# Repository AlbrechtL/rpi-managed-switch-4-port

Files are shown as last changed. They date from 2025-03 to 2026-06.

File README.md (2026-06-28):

# 4-Port Managed Switch

An open-source 4-port gigabit managed switch HAT based on a Raspberry Pi with OpenWrt support.

**Disclaimer:** This is an ongoing project where some features are not working, and some hardware bugs may exist.

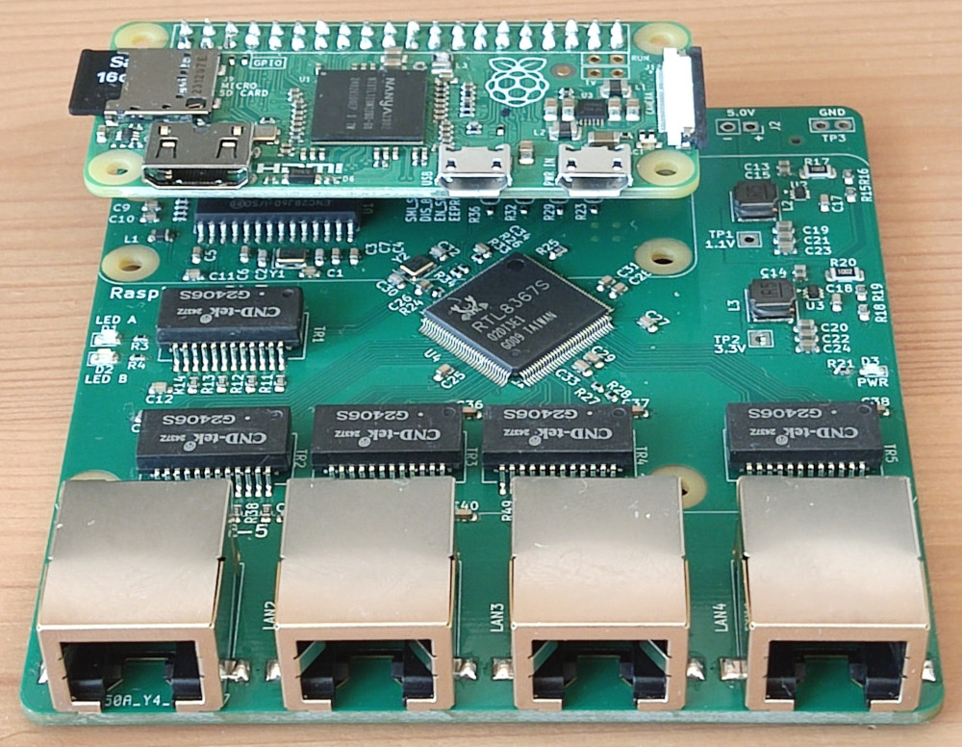
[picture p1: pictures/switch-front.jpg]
4 Port Managed Switch Front


## Features
* 4 Gigabit Ethernet RJ45 ports  
* Supports Raspberry Pi 1–5 (including Raspberry Pi Zero 1–2)  
  - Tested with a Raspberry Pi Zero 1  
  - Raspberry Pi 5 is not working with OpenWrt due to this [issue](https://github.com/openwrt/openwrt/issues/18034)  
* Works with a [custom OpenWrt](https://github.com/AlbrechtL/rpi-managed-switch-openwrt/tree/rpi_managed_switch)  
* Supported by Linux [Distributed Switch Architecture (DSA)](https://www.kernel.org/doc/Documentation/networking/dsa/dsa.txt)  
* VLAN support
* Switching hardware offloading support 
* Hardware design in KiCad
* Ready for JLCPCB production
  - Using a much as possible basic parts to lower the assembling costs

## Software Status

The hardware works with a adapted OpenWrt: https://github.com/AlbrechtL/openwrt/tree/rpi_managed_switch

I added the following to OpenWrt:  
* Device tree overlays for DSA
* Enabled the ENC28J60 driver 
* Added a small patch to enable the ENC28J60 for DSA  
* Added detection of DSA in the first boot scripts so that OpenWrt uses the switch  

See the differences:  
https://github.com/openwrt/openwrt/compare/main...AlbrechtL:openwrt:rpi_managed_switch  

Communication with the RTL8367S switch chip uses Linux DSA. There is also an OpenWrt-specific driver (`drivers/net/phy/rtl8367b.c`) for OpenWrt's legacy `swconfig` framework, but since OpenWrt is moving to DSA, it does not make sense to use it in this project. That said, this driver does work with this switch.

**Distributed Switch Architecture (DSA)**

The to go Linux driver is: `drivers/net/dsa/realtek/rtl8365mb.c`
* Key aspects:
  - Integrated into the Linux kernel  
  - Mainline RTL8367S support  
  - Works on Raspberry Pi OS with a custom Linux kernel
  - Actively maintained
  - Hardware offloading and VLAN support
    - May be added into Linux 7.2 (https://lore.kernel.org/all/20260606-realtek_forward-v13-0-b9e409687cbe@gmail.com/)
    - Available in mainline OpenWrt (https://github.com/openwrt/openwrt/pull/23738)

DSA Example:
```
root@OpenWrt:~# ip addr
1: lo: <LOOPBACK,UP,LOWER_UP> mtu 65536 qdisc noqueue state UNKNOWN qlen 1000
    link/loopback 00:00:00:00:00:00 brd 00:00:00:00:00:00
    inet 127.0.0.1/8 scope host lo
       valid_lft forever preferred_lft forever
    inet6 ::1/128 scope host 
       valid_lft forever preferred_lft forever
2: eth0: <BROADCAST,MULTICAST,UP,LOWER_UP> mtu 1508 qdisc fq_codel state UP qlen 1000
    link/ether b8:27:eb:8f:43:df brd ff:ff:ff:ff:ff:ff
    inet6 fe80::ba27:ebff:fe8f:43df/64 scope link 
       valid_lft forever preferred_lft forever
3: lan1@eth0: <BROADCAST,MULTICAST,UP,LOWER_UP> mtu 1500 qdisc noqueue master switch state UP qlen 1000
    link/ether b8:27:eb:8f:43:df brd ff:ff:ff:ff:ff:ff
4: lan2@eth0: <NO-CARRIER,BROADCAST,MULTICAST,UP> mtu 1500 qdisc noqueue master switch state DOWN qlen 1000
    link/ether b8:27:eb:8f:43:e0 brd ff:ff:ff:ff:ff:ff
5: lan3@eth0: <NO-CARRIER,BROADCAST,MULTICAST,UP> mtu 1500 qdisc noqueue master switch state DOWN qlen 1000
    link/ether b8:27:eb:8f:43:e1 brd ff:ff:ff:ff:ff:ff
6: lan4@eth0: <BROADCAST,MULTICAST,UP,LOWER_UP> mtu 1500 qdisc noqueue master switch state UP qlen 1000
    link/ether b8:27:eb:8f:43:e2 brd ff:ff:ff:ff:ff:ff
7: switch: <BROADCAST,MULTICAST,UP,LOWER_UP> mtu 1500 qdisc noqueue state UP qlen 1000
    link/ether b8:27:eb:8f:43:df brd ff:ff:ff:ff:ff:ff
    inet6 fe80::ba27:ebff:fe8f:43df/64 scope link 
       valid_lft forever preferred_lft forever
8: switch.1@switch: <BROADCAST,MULTICAST,UP,LOWER_UP> mtu 1500 qdisc noqueue state UP qlen 1000
    link/ether b8:27:eb:8f:43:df brd ff:ff:ff:ff:ff:ff
    inet 192.168.1.1/24 brd 192.168.1.255 scope global switch.1
       valid_lft forever preferred_lft forever
    inet6 fd8d:3fdb:486f::1/60 scope global noprefixroute 
       valid_lft forever preferred_lft forever
    inet6 fe80::ba27:ebff:fe8f:43df/64 scope link 
       valid_lft forever preferred_lft forever
```

OpenWrt DSA screenshot  
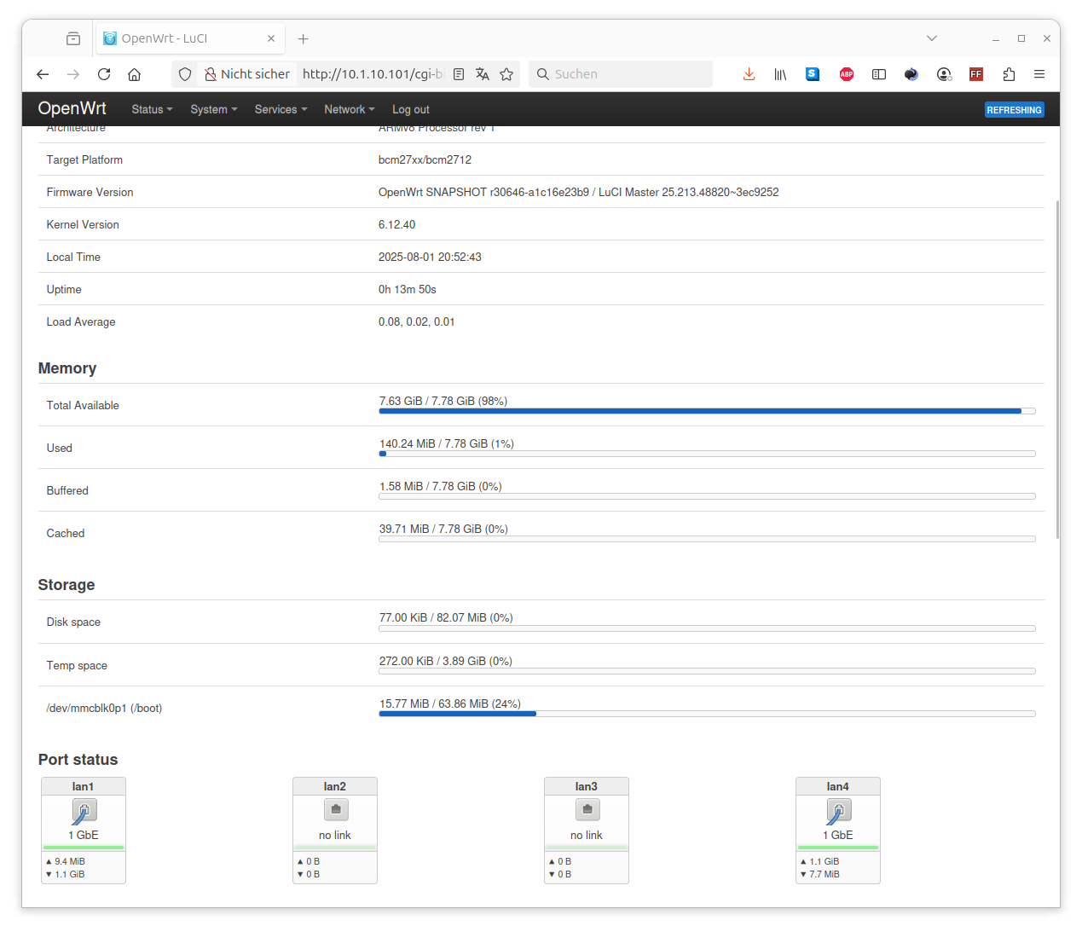
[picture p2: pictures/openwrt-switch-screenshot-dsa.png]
OpenWrt dsa
  

## Hardware Status

I have two assembled PCBs that have basic functionality. See [issues](https://github.com/AlbrechtL/rpi-managed-switch-4-port/issues) for a list of hardware problems.

**Raspberry Pi Zero**
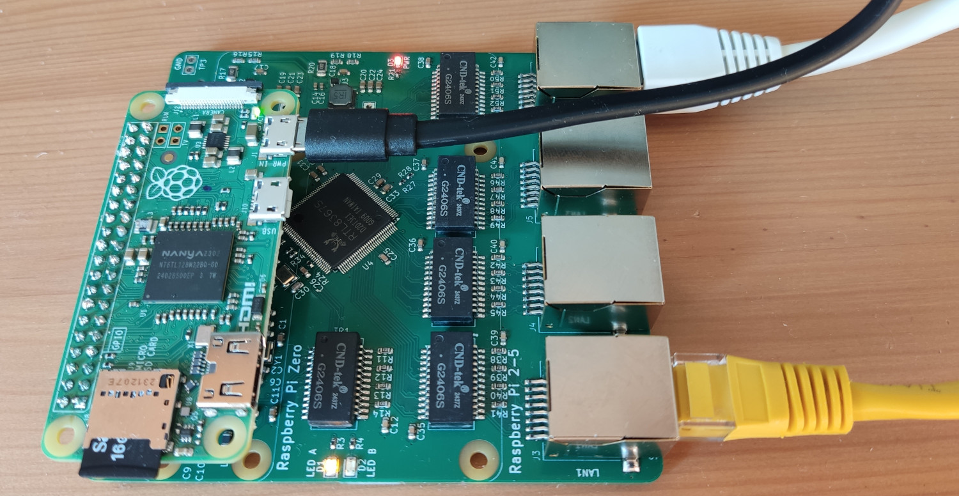
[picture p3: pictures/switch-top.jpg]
4 Port Managed Switch Top


**Raspberry Pi 5**
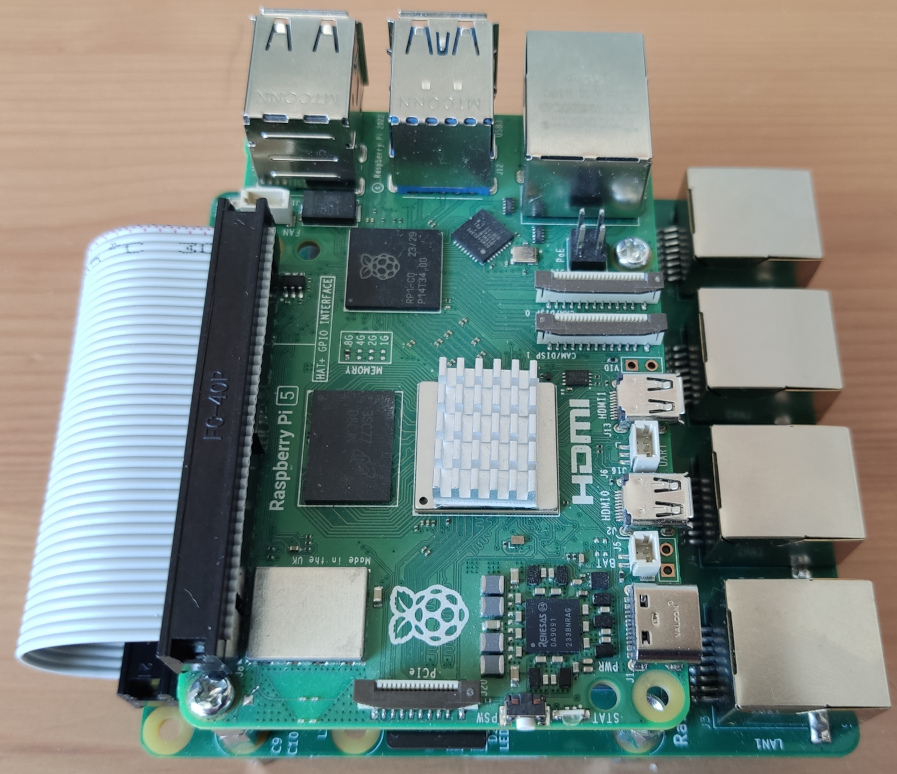
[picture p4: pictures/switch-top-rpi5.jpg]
4 Port Managed Switch Top


## Performance

I don't have detailed performance measurements yet, but here are some bandwidth indications:  
* **RJ45–RJ45 with DSA (rtl8365mb) and offloading patches:** ~1 Gbit/s (wire speed, full-duplex)   
* **RJ45–RJ45 with DSA (rtl8365mb):** ~2 Mbit/s  
  Currently, the RTL8367S DSA driver doesn't support hardware offloading. As a result, all traffic is routed through the Raspberry Pi and the very slow SPI interface. For a switch, this is not acceptable.  
* **Raspberry Pi to RJ45 (CPU port):** ~5 Mbit/s (half-duplex)  
  To support the inexpensive Raspberry Pi Zero, an external SPI Ethernet chip (ENC28J60) is used to connect to the main switch chip (RTL8367S). Due to the slow SPI interface, only ~5 Mbit/s can be achieved. However, for a managed web interface, that's sufficient.  

## Acknowledgements

I would like to thank the following open-source projects. Without these great works, this open-source switch would not be possible:  
* [OpenWrt](https://openwrt.org/)  
* RTL8367S Managed Switch  
  - Blog post: https://blog.brixit.nl/making-a-linux-managed-network-switch/  
  - KiCad: https://github.com/FOSDEM/video/tree/master/hardware/pcbs/switch_board  
* ENC28J60 on a Raspberry Pi Zero  
  - Hackster: https://www.hackster.io/lightside-instruments/the-ethernet4pizero-ethernet-for-raspberry-pi-zero-shield-dd4316  
  - KiCad: https://github.com/lightside-instruments/ethernet4pizero.git  
* [RPI5-CFE-Hat](https://github.com/will127534/RPI5-CFE-Hat)  
* [PCIe3_Hub](https://github.com/will127534/PCIe3_Hub)  
* [RouterPi](https://github.com/ZakKemble/RouterPi)

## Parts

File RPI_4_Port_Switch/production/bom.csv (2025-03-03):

Designator | Footprint | Quantity | Value | LCSC Part #
C1, C10, C11, C17, C18, C25, C26, C27, C28, C29, C31, C33, C34, C35, C36, C37, C38, C4, C5, C6, C7, C9 | 0603 | 22 | 100nF | C14663
C12, C39, C40, C41, C42 | 0603 | 5 | 1nF | C1588
C13, C14, C15, C16, C8 | 0402 | 5 | 10uF | C15525
C19, C20, C21, C22, C23, C24 | 0603 | 6 | 22uF | C59461
C2, C3, C30, C32 | 0603 | 4 | 18pF | C1647
D1 | 0805 | 1 | Yellow | C2296
D2 | 0805 | 1 | Green | C2297
D3 | 0603 | 1 | Red | C2286
H1, H2, H3, H4, H5, H6, H7, H8 | screw_hole | 8 | MountingHole
J1 | PinSocket_2x20_P2.54mm_Vertical_1_04mm | 1 | Raspberry_Pi_2_3
J2 | PinSocket_1x02_P2.54mm_Vertical | 1 | Conn_01x02
J3, J4, J5, J6 | Heling MJ88-B211-JRS3 | 4 | 8P8C_LED | C2895614
L1 | 0805 | 1 | Ferrite Beads | C1015
L2, L3 | L_Taiyo-Yuden_MD-5050 | 2 | 1.5uH | C702825
R1, R17, R2, R20 | 1206 | 4 | 10k | C17902
R10, R7, R8, R9 | 0402 | 4 | 49.9 | C25120
R11, R12, R13, R14, R38, R39, R40, R41, R42, R43, R44, R45, R46, R47, R48, R49, R50, R51, R52, R53 | 0603 | 20 | 75 | C4275
R15 | 0603 | 1 | 3.3k | C22978
R16 | 0603 | 1 | 4.99k | C23046
R18 | 0603 | 1 | 6.2k | C4260
R19 | 0603 | 1 | 39k | C23153
R21, R28, R3, R4 | 0402 | 4 | 470 | C25117
R22, R23, R24, R26, R29, R30, R31, R32, R33, R34, R35, R36, R37 | 0402 | 13 | 4.7k | C25900
R25 | 0603 | 1 | 1k | C21190
R27, R5 | 0402 | 2 | 2k | C4109
R6 | 0402 | 1 | 330 | C25104
TP3 | TestPoint_Bridge_Pitch2.54mm_Drill1.0mm | 1 | Ground point
TR1, TR2, TR3, TR4, TR5 | G2406S | 5 | G2406S | C507595
U1 | SOIC-28W_7.5x17.9mm_P1.27mm | 1 | ENC28J60-I/SO | C47351
U2, U3 | SOT-563 | 2 | TPS562231 | C2070899
U4 | LQFP-128_14x14mm_P0.4mm | 1 | RTL8367S | C2760849
Y1, Y2 | Crystal_SMD_Abracon_ABM8G-4Pin_3.2x2.5mm | 2 | 25Mhz | C9006

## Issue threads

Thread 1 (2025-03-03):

Pull-up resistor at RTL_MDC missing

AlbrechtL, 2025-03-03:
The pull-up resistor at the RTL_MDC line (pin 87 at RTL8367S) is missing. As a result the RTL8367S SMI detection and communication is unstable.

- [x] Fixed in schematic
- [ ] Fixed in PCB

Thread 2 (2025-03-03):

Add USB to Raspberry Pi UART interface

AlbrechtL, 2025-03-03:
To have Ethernet independent access the Raspberry Pi UART pins can be used. When the Raspberry Pi Zero is attached those pins are not accessible easily.

As a convenience feature a USB plug and a USB to UART interface would be really nice.

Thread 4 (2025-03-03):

Add Ethernet LEDs

AlbrechtL, 2025-03-03:
In the first design, the Ethernet LEDs are missing to keep the initial design simple.

In the next design, the Ethernet LEDs shall be existing to give the user feedback about the link status and the activity.

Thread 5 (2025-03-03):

LED brightness too high

AlbrechtL, 2025-03-03:
The brightness of the LEDs "PWR", "RPi ETH Link" and "RPi ETH Activity" are too high. They are dazzling the eyes.

- [ ] Fixed in schematic
- [ ] Fixed in PCB

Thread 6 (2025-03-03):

Use correct part for J1 and J2 connector

AlbrechtL, 2025-03-03:
At the PCB the J1 and J2 connector are using wrong parts. During initial production, this was not an issue because those parts are not assembled by JLCPCB. The footprint itself is working as expected.

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

- [ ] Fixed in schematic
- [ ] Fixed in PCB

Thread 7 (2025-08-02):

LAN3 not working

AlbrechtL, 2025-08-02:
It seems that LAN3 is not working. The reason is unclear - further investigations are needed.

Tested with OpenWrt https://github.com/AlbrechtL/openwrt/tree/rpi_managed_switch and `rtl8365mb.c` patches.

namiltd, 2025-09-09:
change:
```
+		/* 10th register uses only 4 less significant bits (TODO: not tested) */
+		if (val_size == 10)
+			ret = regmap_update_bits(priv->map,
+					RTL8365MB_TABLE_WRITE_DATA_REG_BASE,
+					RTL8365MB_TABLE_10TH_DATA_REG_MASK,
+					FIELD_PREP(RTL8365MB_TABLE_10TH_DATA_REG_MASK, val[9]));
+		if (ret)
+			goto out;
```
to
```
+		/* 10th register uses only 4 less significant bits (TODO: not tested) */
+		if (val_size == 10)
+			ret = regmap_update_bits(priv->map,
+					RTL8365MB_TABLE_WRITE_DATA_REG_BASE + 9,
+					RTL8365MB_TABLE_10TH_DATA_REG_MASK,
+					FIELD_PREP(RTL8365MB_TABLE_10TH_DATA_REG_MASK, val[9]));
+		if (ret)
+			goto out;
```

namiltd, 2025-09-09:
Next test:
```
+	for (vlanmc_idx = 1; vlanmc_idx < RTL8365MB_VLAN_MC_CONF_SIZE; vlanmc_idx++) {
+		ret = regmap_bulk_read(priv->map,
+				       RTL8365MB_VLAN_MC_CONF_REG(vlanmc_idx),
+				       &vlan_entry,
+				       RTL8365MB_VLAN_MC_CONF_ENTRY_SIZE);
+		if (ret) {
+			if (extack)
+				NL_SET_ERR_MSG_MOD(extack,
+						   "Failed to read vlan MC entry");
+			return ret;
+		}
```
to
```
+	for (vlanmc_idx = 1; vlanmc_idx < RTL8365MB_VLAN_MC_CONF_SIZE; vlanmc_idx++) {
+		ret = regmap_bulk_read(priv->map,
+				       RTL8365MB_VLAN_MC_CONF_REG(vlanmc_idx),
+				       vlan_entry,
+				       RTL8365MB_VLAN_MC_CONF_ENTRY_SIZE);
+		if (ret) {
+			if (extack)
+				NL_SET_ERR_MSG_MOD(extack,
+						   "Failed to read vlan MC entry");
+			return ret;
+		}
```

AlbrechtL, 2025-09-09:
I applied all your changes. Still no luck.

But, I'm not sure if I did it correctly. Here is my resulting [rtl8365mb.c](https://github.com/user-attachments/files/22230778/rtl8365mb.c) (kernel 6.12).

AlbrechtL, 2025-09-09:
All other ports are working. Here is my OpenWrt network config. Maybe it is related with the VLAN config.

```
root@OpenWrt:~# cat /etc/config/network

config interface 'loopback'
	option device 'lo'
	option proto 'static'
	list ipaddr '127.0.0.1/8'

config globals 'globals'
	option ula_prefix 'fdbc:dcd7:a884::/48'
	option packet_steering '1'

config device 'switch'
	option name 'switch'
	option type 'bridge'
	option macaddr 'b8:27:eb:8f:43:df'

config bridge-vlan 'lan_vlan'
	option device 'switch'
	option vlan '1'
	option ports 'lan1 lan2 lan3 lan4'

config device
	option name 'switch.1'
	option macaddr 'b8:27:eb:8f:43:df'

config interface 'lan'
	option device 'switch.1'
	option proto 'dhcp'

root@OpenWrt:~#
```

namiltd, 2025-09-09:
`apk add ip-bridge` or `opkg install ip-bridge` and then `bridge vlan show`

namiltd, 2025-09-10:
Everything seems to be fine, but it doesn't work, it's a mystery.

AlbrechtL, 2025-09-10:
Does it work on your TP-Link Archer C5 v4 or EC220-G5 v2 hardware?

namiltd, 2025-09-10:
I'm struggling with frequent crashes on Archer C5 v4 with kernel 6.12 (even without DSA). I   haven't tested the functionality of individual LANs. I'll first resolve the crash issue and then further tests.

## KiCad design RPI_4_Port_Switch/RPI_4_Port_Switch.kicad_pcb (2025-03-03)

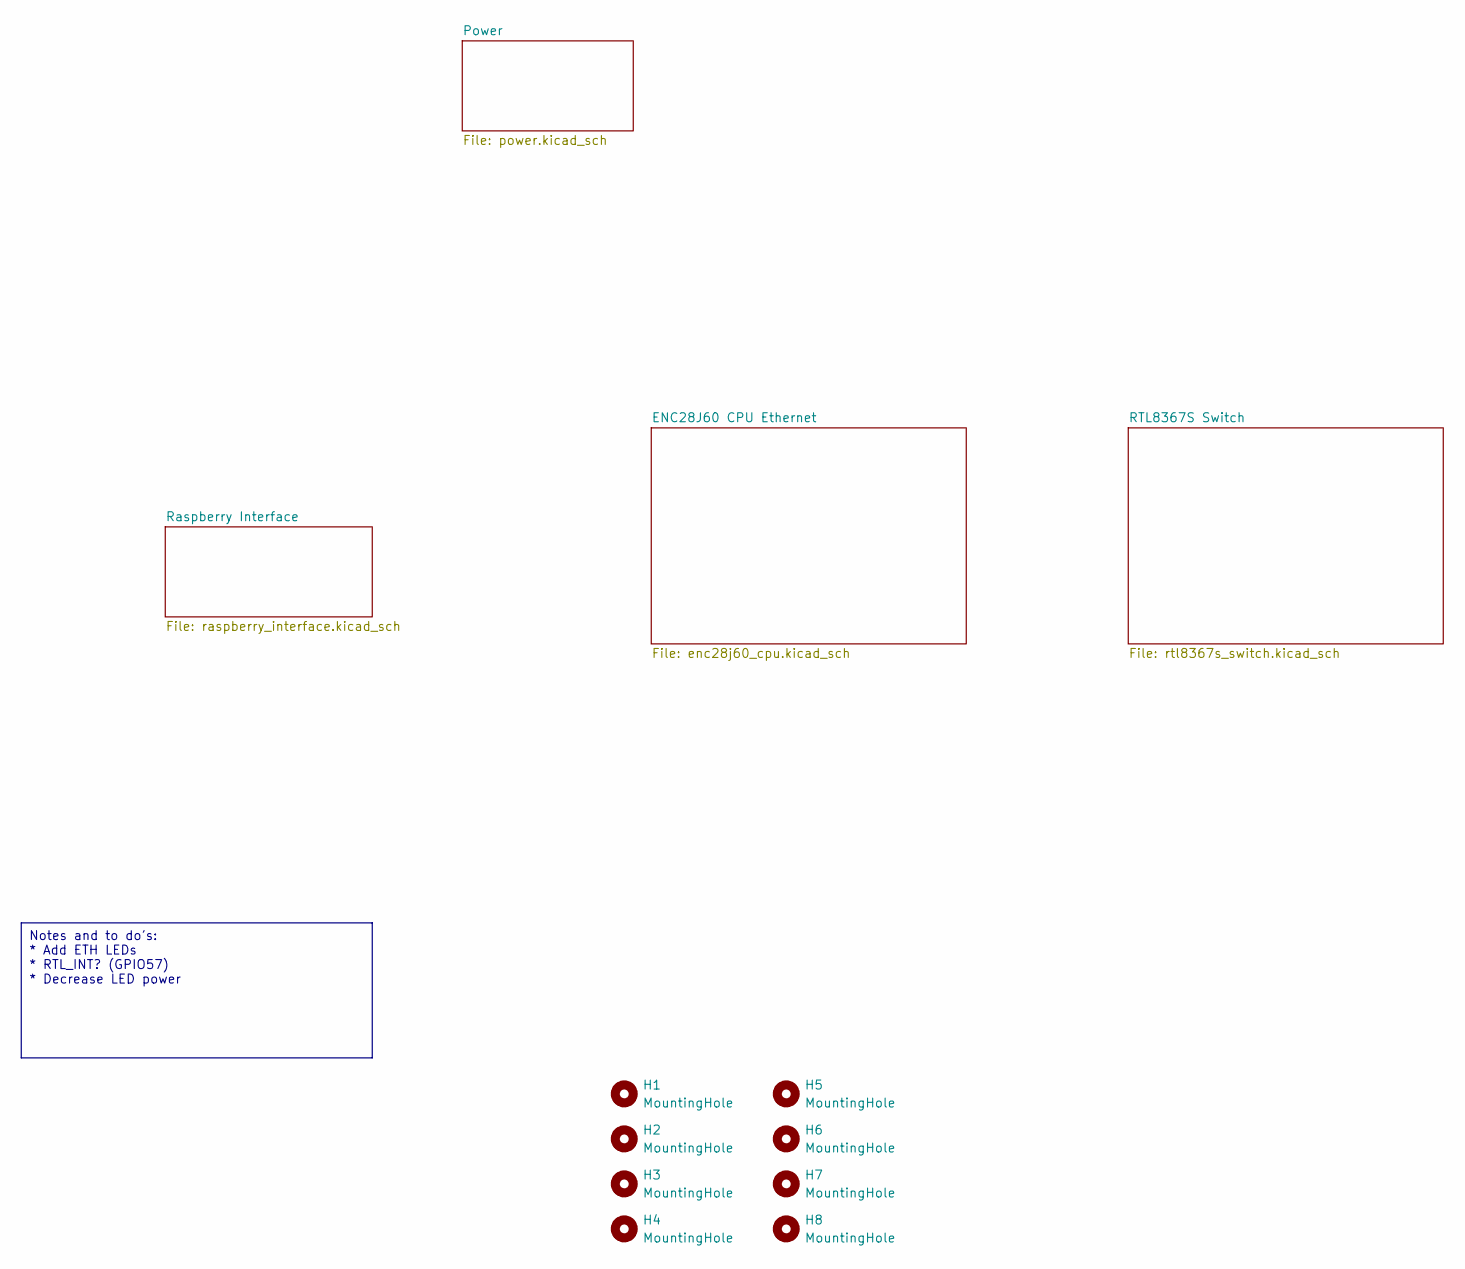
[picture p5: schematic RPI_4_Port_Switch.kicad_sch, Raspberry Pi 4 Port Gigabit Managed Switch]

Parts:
H1, H2, H3, H4, H5, H6, H7, H8: MountingHole; screw_hole

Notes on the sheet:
Notes and to do's: * Add ETH LEDs * RTL_INT? (GPIO57) * Decrease LED power

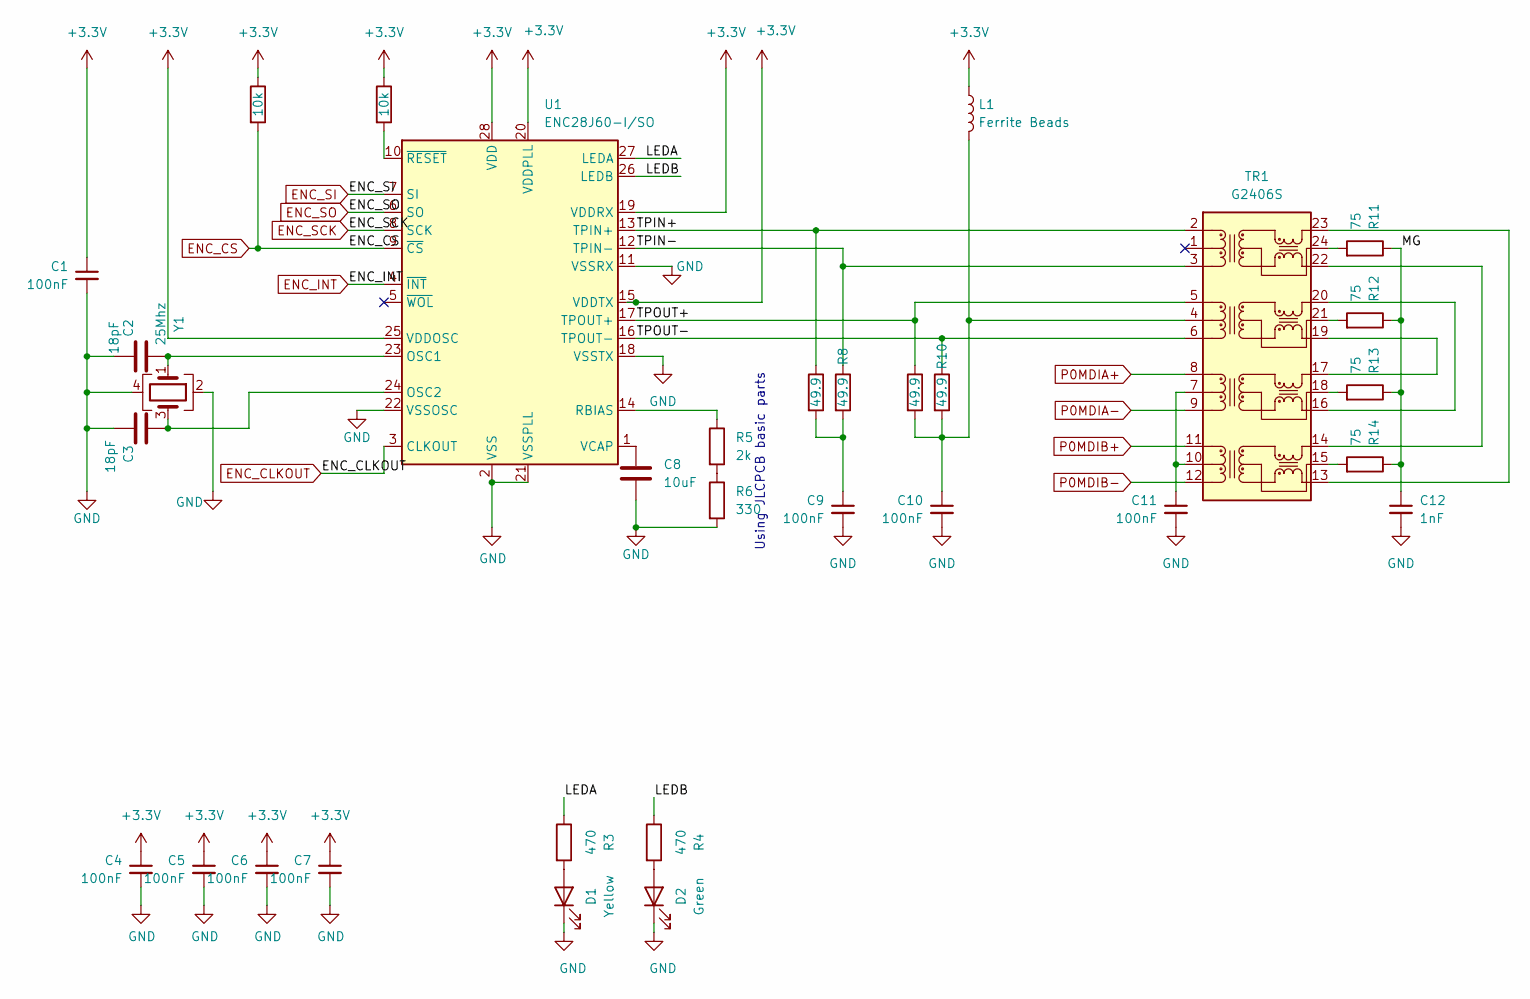
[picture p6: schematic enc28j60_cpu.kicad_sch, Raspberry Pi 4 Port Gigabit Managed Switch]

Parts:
C1, C4, C5, C6, C7, C9, C10, C11: 100nF; C_0603_1608Metric; Part 50V 100nF X7R ±10% 0603; LCSC Part # C14663
C2, C3: 18pF; C_0603_1608Metric; Part 50V 18pF C0G ±5% 0603; LCSC Part # C1647
C8: 10uF; C_0402_1005Metric; Part 6.3V 10uF X5R ±20% 0402; LCSC Part # C15525
C12: 1nF; C_0603_1608Metric; Part 50V 1nF X7R ±10% 0603; LCSC Part # C1588
D1: Yellow; LED_0805_2012Metric; Part Yellow 0805 LED Indication; LCSC Part # C2296
D2: Green; LED_0805_2012Metric; Part Emerald 0805 LED Indication (green); LCSC Part # C2297
L1: Ferrite Beads; L_0805_2012Metric; LCSC Part # C1015
R1, R2: 10k; R_1206_3216Metric; Part 250mW Thick Film Resistors 200V ±100ppm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; LCSC Part # C17902
R3, R4: 470; R_0402_1005Metric; Part 62.5mW Thick Film Resistors 50V ±100ppm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; LCSC Part # C25117
R5: 2k; R_0402_1005Metric; Part 62.5mW Thick Film Resistors 50V ±100ppm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; LCSC Part # C4109
R6: 330; R_0402_1005Metric; Part 62.5mW Thick Film Resistors 50V ±100ppm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; LCSC Part # C25104
R7, R8, R9, R10: 49.9; R_0402_1005Metric; Part 62.5mW Thick Film Resistors 50V ±100ppm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; LCSC Part # C25120
R11, R12, R13, R14: 75; R_0603_1608Metric; Part R 75Ω 125mW 1% 0603; LCSC Part # C4275
TR1: G2406S; Part G2406S; LCSC Part # C507595
U1: ENC28J60-I/SO; SOIC-28W_7.5x17.9mm_P1.27mm; LCSC Part # C47351
Y1: 25Mhz; Crystal_SMD_Abracon_ABM8G-4Pin_3.2x2.5mm; LCSC Part # C9006

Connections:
+3.3V: C1.1, C4.1, C5.1, C6.1, C7.1, L1.1, R1.1, R2.1, U1.15 (VDDTX), U1.19 (VDDRX), U1.20 (VDDPLL), U1.25 (VDDOSC), U1.28 (VDD); also elsewhere on the board
/ENC28J60 CPU Ethernet/LEDA: R3.1, U1.27 (LEDA)
/ENC28J60 CPU Ethernet/LEDB: R4.1, U1.26 (LEDB)
/ENC28J60 CPU Ethernet/MG: C12.1, R11.1, R12.1, R13.1, R14.1
/ENC28J60 CPU Ethernet/TPIN+: R7.1, TR1.2 (TD1+), U1.13 (TPIN+)
/ENC28J60 CPU Ethernet/TPIN-: R8.1, TR1.3 (TD1-), U1.12 (TPIN-)
/ENC28J60 CPU Ethernet/TPOUT+: R9.1, TR1.5 (TD2+), U1.17 (TPOUT+)
/ENC28J60 CPU Ethernet/TPOUT-: R10.1, TR1.6 (TD2-), U1.16 (TPOUT-)
ENC_CLKOUT: U1.3 (CLKOUT); also elsewhere on the board
ENC_CS: R1.2, U1.9 (~CS); also elsewhere on the board
ENC_INT: U1.4 (~INT); also elsewhere on the board
ENC_SCK: U1.8 (SCK); also elsewhere on the board
ENC_SI: U1.7 (SI); also elsewhere on the board
ENC_SO: U1.6 (SO); also elsewhere on the board
GND: C1.2, C2.2, C3.2, C4.2, C5.2, C6.2, C7.2, C8.2, C9.2, C10.2, C11.2, C12.2, D1.1 (K), D2.1 (K), R6.2, U1.2 (VSS), U1.11 (VSSRX), U1.18 (VSSTX), U1.21 (VSSPLL), U1.22 (VSSOSC), Y1.2, Y1.4; also elsewhere on the board
unnamed: C9.1, R7.2, R8.2
unnamed: C10.1, L1.2, R9.2, R10.2, TR1.4 (CT)
unnamed: C11.1, TR1.7 (CT), TR1.10 (CT)
unnamed: D1.2 (A), R3.2
unnamed: D2.2 (A), R4.2
unnamed: R5.2, R6.1
unnamed: R11.2, TR1.24 (CT)
unnamed: R12.2, TR1.21 (CT)
unnamed: R13.2, TR1.18 (CT)
unnamed: R14.2, TR1.15 (CT)
unnamed: TR1.13 (MX4-), TR1.23 (MX1+)
unnamed: TR1.14 (MX4+), TR1.22 (MX1-)
unnamed: TR1.16 (MX3-), TR1.20 (MX2+)
unnamed: TR1.17 (MX3+), TR1.19 (MX2-)
unnamed: C2.1, U1.23 (OSC1), Y1.1
unnamed: C3.1, U1.24 (OSC2), Y1.3
unnamed: R5.1, U1.14 (RBIAS)
unnamed: C8.1, U1.1 (VCAP)
unnamed: R2.2, U1.10 (~RESET)
P0MDIA+: TR1.8 (TD3+); also elsewhere on the board
P0MDIA-: TR1.9 (TD3-); also elsewhere on the board
P0MDIB+: TR1.11 (TD4+); also elsewhere on the board
P0MDIB-: TR1.12 (TD4-); also elsewhere on the board

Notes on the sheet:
Using JLCPCB basic parts

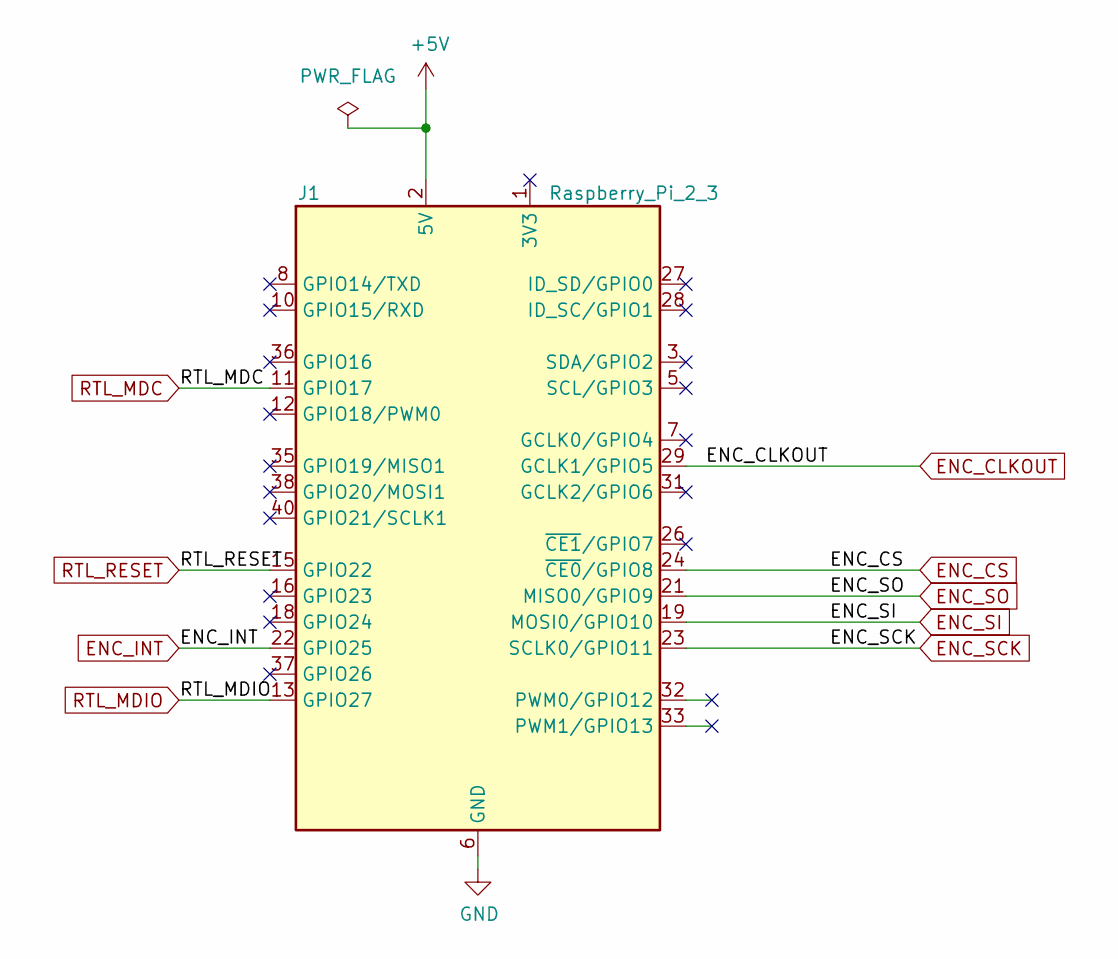
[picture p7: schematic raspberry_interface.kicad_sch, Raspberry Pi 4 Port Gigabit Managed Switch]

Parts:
J1: Raspberry_Pi_2_3; PinSocket_2x20_P2.54mm_Vertical_1_04mm

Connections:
+5V: J1.2 (5V), J1.4 (5V); also elsewhere on the board
ENC_CLKOUT: J1.29 (GCLK1/GPIO5); also elsewhere on the board
ENC_CS: J1.24 (~CE0/GPIO8); also elsewhere on the board
ENC_INT: J1.22 (GPIO25); also elsewhere on the board
ENC_SCK: J1.23 (SCLK0/GPIO11); also elsewhere on the board
ENC_SI: J1.19 (MOSI0/GPIO10); also elsewhere on the board
ENC_SO: J1.21 (MISO0/GPIO9); also elsewhere on the board
GND: J1.6 (GND), J1.9 (GND), J1.14 (GND), J1.20 (GND), J1.25 (GND), J1.30 (GND), J1.34 (GND), J1.39 (GND); also elsewhere on the board
RTL_MDC: J1.11 (GPIO17); also elsewhere on the board
RTL_MDIO: J1.13 (GPIO27); also elsewhere on the board
RTL_RESET: J1.15 (GPIO22); also elsewhere on the board

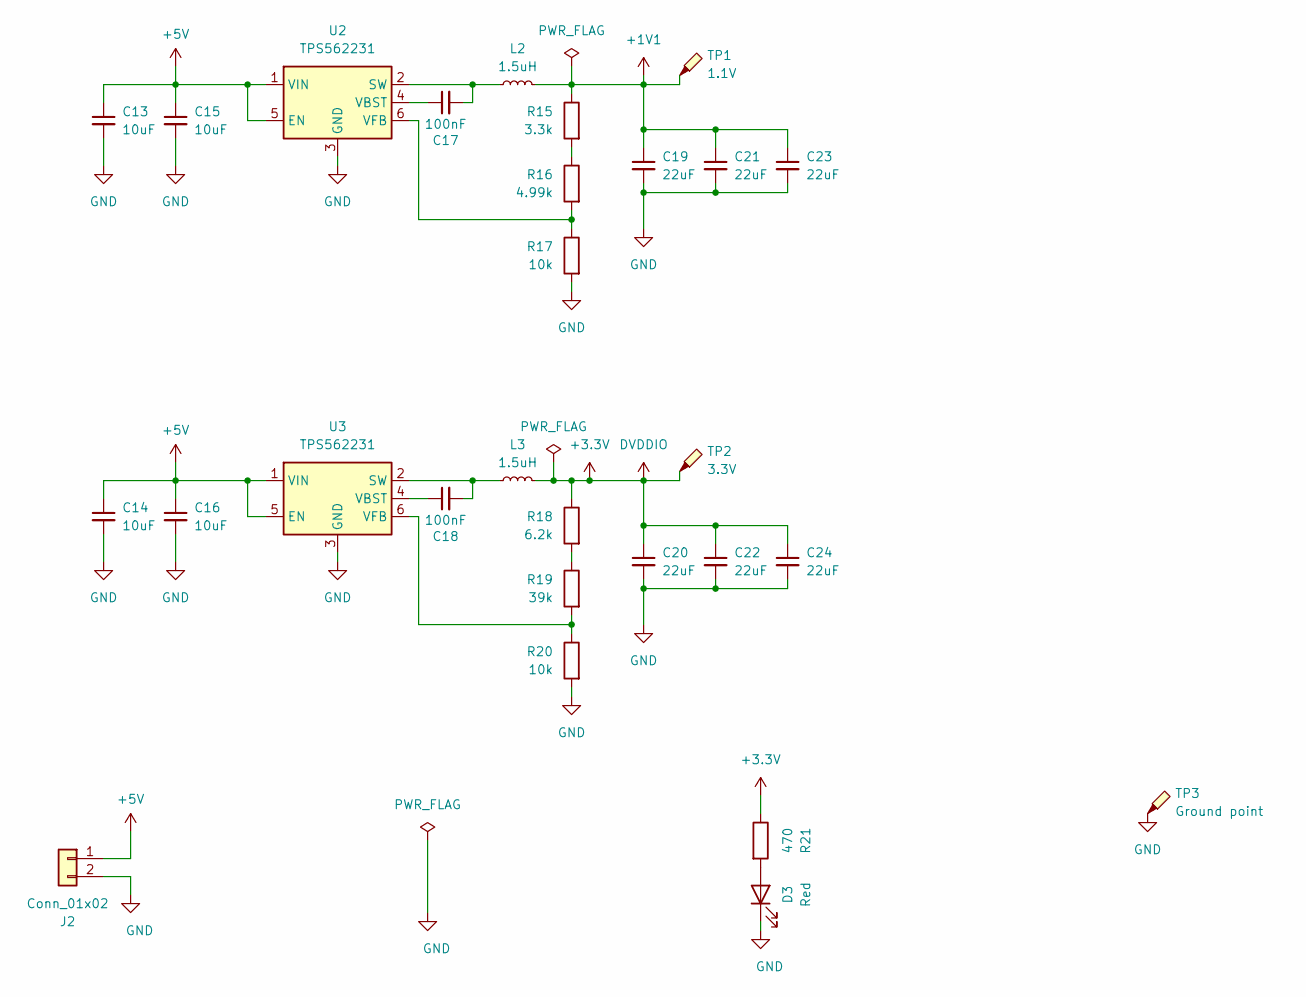
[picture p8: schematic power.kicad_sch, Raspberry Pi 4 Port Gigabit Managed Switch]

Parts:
C13, C14, C15, C16: 10uF; C_0402_1005Metric; Part 6.3V 10uF X5R ±20% 0402; LCSC Part # C15525
C17, C18: 100nF; C_0603_1608Metric; Part 50V 100nF X7R ±10% 0603; LCSC Part # C14663
C19, C20, C21, C22, C23, C24: 22uF; C_0603_1608Metric; Part 6.3V 22uF X5R ±20% 0603; LCSC Part # C59461
D3: Red; LED_0603_1608Metric; Part LED Red 0603; LCSC Part # C2286
J2: Conn_01x02; PinSocket_1x02_P2.54mm_Vertical
L2, L3: 1.5uH; L_Taiyo-Yuden_MD-5050; Part BWVF005050201R5T00 or 74404054015; LCSC Part # C702825
R15: 3.3k; R_0603_1608Metric; Part R 3.3kΩ 125mW 1% 0603; LCSC Part # C22978
R16: 4.99k; R_0603_1608Metric; Part R 4.99kΩ 125mW 1% 0603; LCSC Part # C23046
R17, R20: 10k; R_1206_3216Metric; Part 250mW Thick Film Resistors 200V ±100ppm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; LCSC Part # C17902
R18: 6.2k; R_0603_1608Metric; Part R 6.2kΩ 125mW 1% 0603; LCSC Part # C4260
R19: 39k; R_0603_1608Metric; Part R 39kΩ 125mW 1% 0603; LCSC Part # C23153
R21: 470; R_0402_1005Metric; Part 62.5mW Thick Film Resistors 50V ±100ppm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; LCSC Part # C25117
TP1: 1.1V; TestPoint_THTPad_2.0x2.0mm_Drill1.0mm
TP2: 3.3V; TestPoint_THTPad_2.0x2.0mm_Drill1.0mm
TP3: Ground point; TestPoint_Bridge_Pitch2.54mm_Drill1.0mm
U2, U3: TPS562231; SOT-563; Part TPS562231DRLR; LCSC Part # C2070899

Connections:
+1V1: C19.1, C21.1, C23.1, L2.2, R15.1, TP1.1; also elsewhere on the board
+3.3V: C20.1, C22.1, C24.1, L3.2, R18.1, R21.1, TP2.1; also elsewhere on the board
+5V: C13.1, C14.1, C15.1, C16.1, J2.1, U2.1 (VIN), U2.5 (EN), U3.1 (VIN), U3.5 (EN); also elsewhere on the board
GND: C13.2, C14.2, C15.2, C16.2, C19.2, C20.2, C21.2, C22.2, C23.2, C24.2, D3.1 (K), J2.2, R17.2, R20.2, TP3.1, U2.3 (GND), U3.3 (GND); also elsewhere on the board
unnamed: D3.2 (A), R21.2
unnamed: R15.2, R16.1
unnamed: R18.2, R19.1
unnamed: C17.2, L2.1, U2.2 (SW)
unnamed: C17.1, U2.4 (VBST)
unnamed: R16.2, R17.1, U2.6 (VFB)
unnamed: C18.2, L3.1, U3.2 (SW)
unnamed: C18.1, U3.4 (VBST)
unnamed: R19.2, R20.1, U3.6 (VFB)

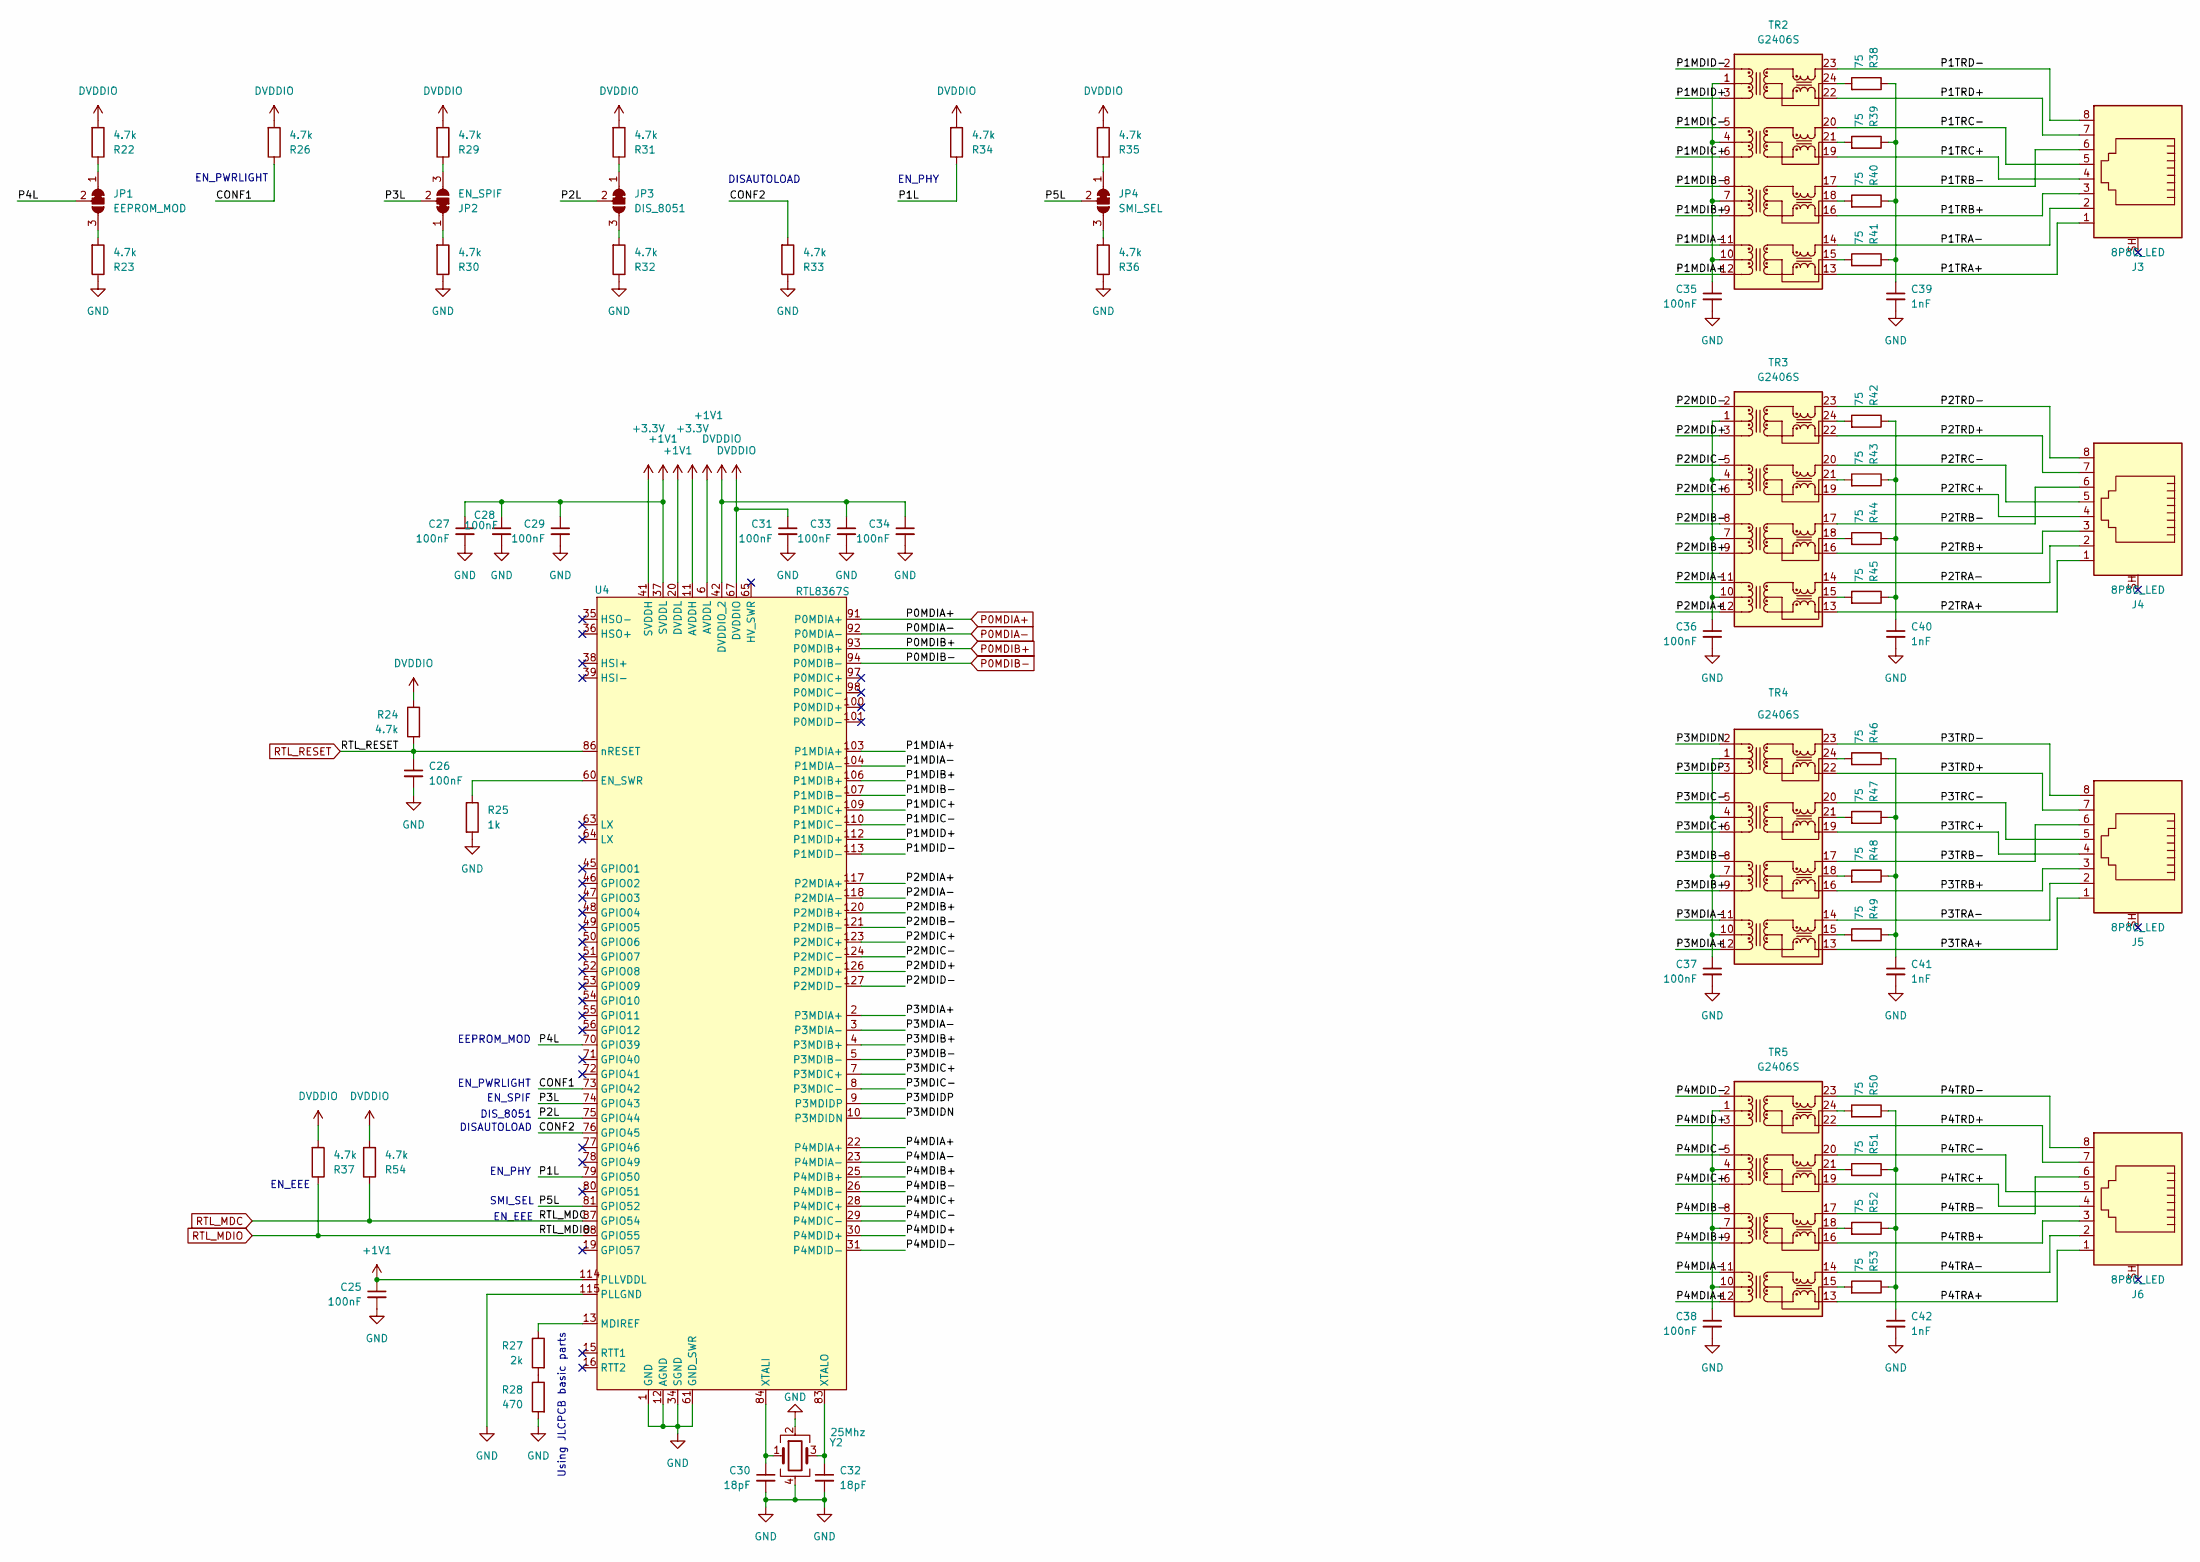
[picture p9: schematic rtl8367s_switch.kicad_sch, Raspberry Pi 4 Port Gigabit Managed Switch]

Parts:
C25, C26, C27, C28, C29, C31, C33, C34, C35, C36, C37, C38: 100nF; C_0603_1608Metric; Part 50V 100nF X7R ±10% 0603; LCSC Part # C14663
C30, C32: 18pF; C_0603_1608Metric; Part 50V 18pF C0G ±5% 0603; LCSC Part # C1647
C39, C40, C41, C42: 1nF; C_0603_1608Metric; Part 50V 1nF X7R ±10% 0603; LCSC Part # C1588
J3, J4, J5, J6: 8P8C_LED; Heling MJ88-B211-JRS3; Part MJ88-B211-JRS3; LCSC Part # C2895614
JP1: EEPROM_MOD; SolderJumper-3_P1.3mm_Bridged12_RoundedPad1.0x1.5mm
JP2: EN_SPIF; SolderJumper-3_P1.3mm_Bridged12_RoundedPad1.0x1.5mm
JP3: DIS_8051; SolderJumper-3_P1.3mm_Bridged12_RoundedPad1.0x1.5mm
JP4: SMI_SEL; SolderJumper-3_P1.3mm_Bridged12_RoundedPad1.0x1.5mm
R22, R23, R24, R26, R29, R30, R31, R32, R33, R34, R35, R36, R37, R54: 4.7k; R_0402_1005Metric; LCSC Part # C25900
R25: 1k; R_0603_1608Metric; Part R 1kΩ 125mW 1% 0603; LCSC Part # C21190
R27: 2k; R_0402_1005Metric; Part 62.5mW Thick Film Resistors 50V ±100ppm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; LCSC Part # C4109
R28: 470; R_0402_1005Metric; Part 62.5mW Thick Film Resistors 50V ±100ppm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; LCSC Part # C25117
R38, R39, R40, R41, R42, R43, R44, R45, R46, R47, R48, R49, R50, R51, R52, R53: 75; R_0603_1608Metric; Part R 75Ω 125mW 1% 0603; LCSC Part # C4275
TR2, TR3, TR4, TR5: G2406S; Part G2406S; LCSC Part # C507595
U4: RTL8367S; LQFP-128_14x14mm_P0.4mm; Part RTL8367S; LCSC Part # C2760849
Y2: 25Mhz; Crystal_SMD_Abracon_ABM8G-4Pin_3.2x2.5mm; LCSC Part # C9006

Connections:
+1V1: C25.1, C27.1, C28.1, C29.1, U4.6 (AVDDL), U4.14 (AVDDL), U4.20 (DVDDL), U4.27 (AVDDL), U4.37 (SVDDL), U4.58 (DVDDL), U4.69 (DVDDL), U4.95 (AVDDL), U4.108 (AVDDL), U4.114 (PLLVDDL), U4.122 (AVDDL); also elsewhere on the board
+3.3V: C31.1, C33.1, C34.1, R22.2, R24.1, R26.2, R29.2, R31.2, R34.2, R35.2, R37.2, R54.2, U4.11 (AVDDH), U4.17 (AVDDH), U4.21 (AVDDH), U4.33 (AVDDH), U4.41 (SVDDH), U4.42 (DVDDIO_2), U4.59 (DVDDIO_2), U4.67 (DVDDIO), U4.82 (AVDDH), U4.90 (AVDDH), U4.102 (AVDDH), U4.116 (AVDDH), U4.128 (AVDDH); also elsewhere on the board
/RTL8367S Switch/CONF1: R26.1, U4.73 (GPIO42)
/RTL8367S Switch/CONF2: R33.2, U4.76 (GPIO45)
/RTL8367S Switch/P1L: R34.1, U4.79 (GPIO50)
/RTL8367S Switch/P1MDIA+: TR2.12 (TD4-), U4.103 (P1MDIA+)
/RTL8367S Switch/P1MDIA-: TR2.11 (TD4+), U4.104 (P1MDIA-)
/RTL8367S Switch/P1MDIB+: TR2.9 (TD3-), U4.106 (P1MDIB+)
/RTL8367S Switch/P1MDIB-: TR2.8 (TD3+), U4.107 (P1MDIB-)
/RTL8367S Switch/P1MDIC+: TR2.6 (TD2-), U4.109 (P1MDIC+)
/RTL8367S Switch/P1MDIC-: TR2.5 (TD2+), U4.110 (P1MDIC-)
/RTL8367S Switch/P1MDID+: TR2.3 (TD1-), U4.112 (P1MDID+)
/RTL8367S Switch/P1MDID-: TR2.2 (TD1+), U4.113 (P1MDID-)
/RTL8367S Switch/P1TRA+: J3.1, TR2.13 (MX4-)
/RTL8367S Switch/P1TRA-: J3.2, TR2.14 (MX4+)
/RTL8367S Switch/P1TRB+: J3.3, TR2.16 (MX3-)
/RTL8367S Switch/P1TRB-: J3.6, TR2.17 (MX3+)
/RTL8367S Switch/P1TRC+: J3.4, TR2.19 (MX2-)
/RTL8367S Switch/P1TRC-: J3.5, TR2.20 (MX2+)
/RTL8367S Switch/P1TRD+: J3.7, TR2.22 (MX1-)
/RTL8367S Switch/P1TRD-: J3.8, TR2.23 (MX1+)
/RTL8367S Switch/P2L: JP3.2 (C), U4.75 (GPIO44)
/RTL8367S Switch/P2MDIA+: TR3.12 (TD4-), U4.117 (P2MDIA+)
/RTL8367S Switch/P2MDIA-: TR3.11 (TD4+), U4.118 (P2MDIA-)
/RTL8367S Switch/P2MDIB+: TR3.9 (TD3-), U4.120 (P2MDIB+)
/RTL8367S Switch/P2MDIB-: TR3.8 (TD3+), U4.121 (P2MDIB-)
/RTL8367S Switch/P2MDIC+: TR3.6 (TD2-), U4.123 (P2MDIC+)
/RTL8367S Switch/P2MDIC-: TR3.5 (TD2+), U4.124 (P2MDIC-)
/RTL8367S Switch/P2MDID+: TR3.3 (TD1-), U4.126 (P2MDID+)
/RTL8367S Switch/P2MDID-: TR3.2 (TD1+), U4.127 (P2MDID-)
/RTL8367S Switch/P2TRA+: J4.1, TR3.13 (MX4-)
/RTL8367S Switch/P2TRA-: J4.2, TR3.14 (MX4+)
/RTL8367S Switch/P2TRB+: J4.3, TR3.16 (MX3-)
/RTL8367S Switch/P2TRB-: J4.6, TR3.17 (MX3+)
/RTL8367S Switch/P2TRC+: J4.4, TR3.19 (MX2-)
/RTL8367S Switch/P2TRC-: J4.5, TR3.20 (MX2+)
/RTL8367S Switch/P2TRD+: J4.7, TR3.22 (MX1-)
/RTL8367S Switch/P2TRD-: J4.8, TR3.23 (MX1+)
/RTL8367S Switch/P3L: JP2.2 (C), U4.74 (GPIO43)
/RTL8367S Switch/P3MDIA+: TR4.12 (TD4-), U4.2 (P3MDIA+)
/RTL8367S Switch/P3MDIA-: TR4.11 (TD4+), U4.3 (P3MDIA-)
/RTL8367S Switch/P3MDIB+: TR4.9 (TD3-), U4.4 (P3MDIB+)
/RTL8367S Switch/P3MDIB-: TR4.8 (TD3+), U4.5 (P3MDIB-)
/RTL8367S Switch/P3MDIC+: TR4.6 (TD2-), U4.7 (P3MDIC+)
/RTL8367S Switch/P3MDIC-: TR4.5 (TD2+), U4.8 (P3MDIC-)
/RTL8367S Switch/P3MDIDN: TR4.2 (TD1+), U4.10 (P3MDIDN)
/RTL8367S Switch/P3MDIDP: TR4.3 (TD1-), U4.9 (P3MDIDP)
/RTL8367S Switch/P3TRA+: J5.1, TR4.13 (MX4-)
/RTL8367S Switch/P3TRA-: J5.2, TR4.14 (MX4+)
/RTL8367S Switch/P3TRB+: J5.3, TR4.16 (MX3-)
/RTL8367S Switch/P3TRB-: J5.6, TR4.17 (MX3+)
/RTL8367S Switch/P3TRC+: J5.4, TR4.19 (MX2-)
/RTL8367S Switch/P3TRC-: J5.5, TR4.20 (MX2+)
/RTL8367S Switch/P3TRD+: J5.7, TR4.22 (MX1-)
/RTL8367S Switch/P3TRD-: J5.8, TR4.23 (MX1+)
/RTL8367S Switch/P4L: JP1.2 (C), U4.70 (GPIO39)
/RTL8367S Switch/P4MDIA+: TR5.12 (TD4-), U4.22 (P4MDIA+)
/RTL8367S Switch/P4MDIA-: TR5.11 (TD4+), U4.23 (P4MDIA-)
/RTL8367S Switch/P4MDIB+: TR5.9 (TD3-), U4.25 (P4MDIB+)
/RTL8367S Switch/P4MDIB-: TR5.8 (TD3+), U4.26 (P4MDIB-)
/RTL8367S Switch/P4MDIC+: TR5.6 (TD2-), U4.28 (P4MDIC+)
/RTL8367S Switch/P4MDIC-: TR5.5 (TD2+), U4.29 (P4MDIC-)
/RTL8367S Switch/P4MDID+: TR5.3 (TD1-), U4.30 (P4MDID+)
/RTL8367S Switch/P4MDID-: TR5.2 (TD1+), U4.31 (P4MDID-)
/RTL8367S Switch/P4TRA+: J6.1, TR5.13 (MX4-)
/RTL8367S Switch/P4TRA-: J6.2, TR5.14 (MX4+)
/RTL8367S Switch/P4TRB+: J6.3, TR5.16 (MX3-)
/RTL8367S Switch/P4TRB-: J6.6, TR5.17 (MX3+)
/RTL8367S Switch/P4TRC+: J6.4, TR5.19 (MX2-)
/RTL8367S Switch/P4TRC-: J6.5, TR5.20 (MX2+)
/RTL8367S Switch/P4TRD+: J6.7, TR5.22 (MX1-)
/RTL8367S Switch/P4TRD-: J6.8, TR5.23 (MX1+)
/RTL8367S Switch/P5L: JP4.2 (C), U4.81 (GPIO52)
GND: C25.2, C26.2, C27.2, C28.2, C29.2, C30.2, C31.2, C32.2, C33.2, C34.2, C35.2, C36.2, C37.2, C38.2, C39.2, C40.2, C41.2, C42.2, R23.1, R25.2, R28.2, R30.1, R32.1, R33.1, R36.1, U4.1 (GND), U4.12 (AGND), U4.18 (GND), U4.24 (GND), U4.32 (GND), U4.34 (SGND), U4.40 (SGND), U4.43 (GND), U4.44 (GND), U4.57 (GND), U4.61 (GND_SWR), U4.62 (GND_SWR), U4.68 (GND), U4.85 (GND), U4.89 (GND), U4.96 (GND), U4.99 (GND), U4.105 (GND), U4.111 (GND), U4.115 (PLLGND), U4.119 (GND), U4.125 (GND), Y2.2, Y2.4; also elsewhere on the board
unnamed: C35.1, TR2.1 (CT), TR2.4 (CT), TR2.7 (CT), TR2.10 (CT)
unnamed: C36.1, TR3.1 (CT), TR3.4 (CT), TR3.7 (CT), TR3.10 (CT)
unnamed: C37.1, TR4.1 (CT), TR4.4 (CT), TR4.7 (CT), TR4.10 (CT)
unnamed: C38.1, TR5.1 (CT), TR5.4 (CT), TR5.7 (CT), TR5.10 (CT)
unnamed: C39.1, R38.1, R39.1, R40.1, R41.1
unnamed: C40.1, R42.1, R43.1, R44.1, R45.1
unnamed: C41.1, R46.1, R47.1, R48.1, R49.1
unnamed: C42.1, R50.1, R51.1, R52.1, R53.1
unnamed: JP1.1 (A), R22.1
unnamed: JP1.3 (B), R23.2
unnamed: JP2.1 (A), R30.2
unnamed: JP2.3 (B), R29.1
unnamed: JP3.1 (A), R31.1
unnamed: JP3.3 (B), R32.2
unnamed: JP4.1 (A), R35.1
unnamed: JP4.3 (B), R36.2
unnamed: R27.2, R28.1
unnamed: R38.2, TR2.24 (CT)
unnamed: R39.2, TR2.21 (CT)
unnamed: R40.2, TR2.18 (CT)
unnamed: R41.2, TR2.15 (CT)
unnamed: R42.2, TR3.24 (CT)
unnamed: R43.2, TR3.21 (CT)
unnamed: R44.2, TR3.18 (CT)
unnamed: R45.2, TR3.15 (CT)
unnamed: R46.2, TR4.24 (CT)
unnamed: R47.2, TR4.21 (CT)
unnamed: R48.2, TR4.18 (CT)
unnamed: R49.2, TR4.15 (CT)
unnamed: R50.2, TR5.24 (CT)
unnamed: R51.2, TR5.21 (CT)
unnamed: R52.2, TR5.18 (CT)
unnamed: R53.2, TR5.15 (CT)
unnamed: R25.1, U4.60 (EN_SWR)
unnamed: R27.1, U4.13 (MDIREF)
unnamed: C30.1, U4.84 (XTALI), Y2.1
unnamed: C32.1, U4.83 (XTALO), Y2.3
P0MDIA+: U4.91 (P0MDIA+); also elsewhere on the board
P0MDIA-: U4.92 (P0MDIA-); also elsewhere on the board
P0MDIB+: U4.93 (P0MDIB+); also elsewhere on the board
P0MDIB-: U4.94 (P0MDIB-); also elsewhere on the board
RTL_MDC: R54.1, U4.87 (GPIO54); also elsewhere on the board
RTL_MDIO: R37.1, U4.88 (GPIO55); also elsewhere on the board
RTL_RESET: C26.1, R24.2, U4.86 (nRESET); also elsewhere on the board

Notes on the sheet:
DIS_8051
EN_EEE
EEPROM_MOD
Using JLCPCB basic parts
EN_PWRLIGHT
SMI_SEL
EN_SPIF
DISAUTOLOAD
EN_PHY

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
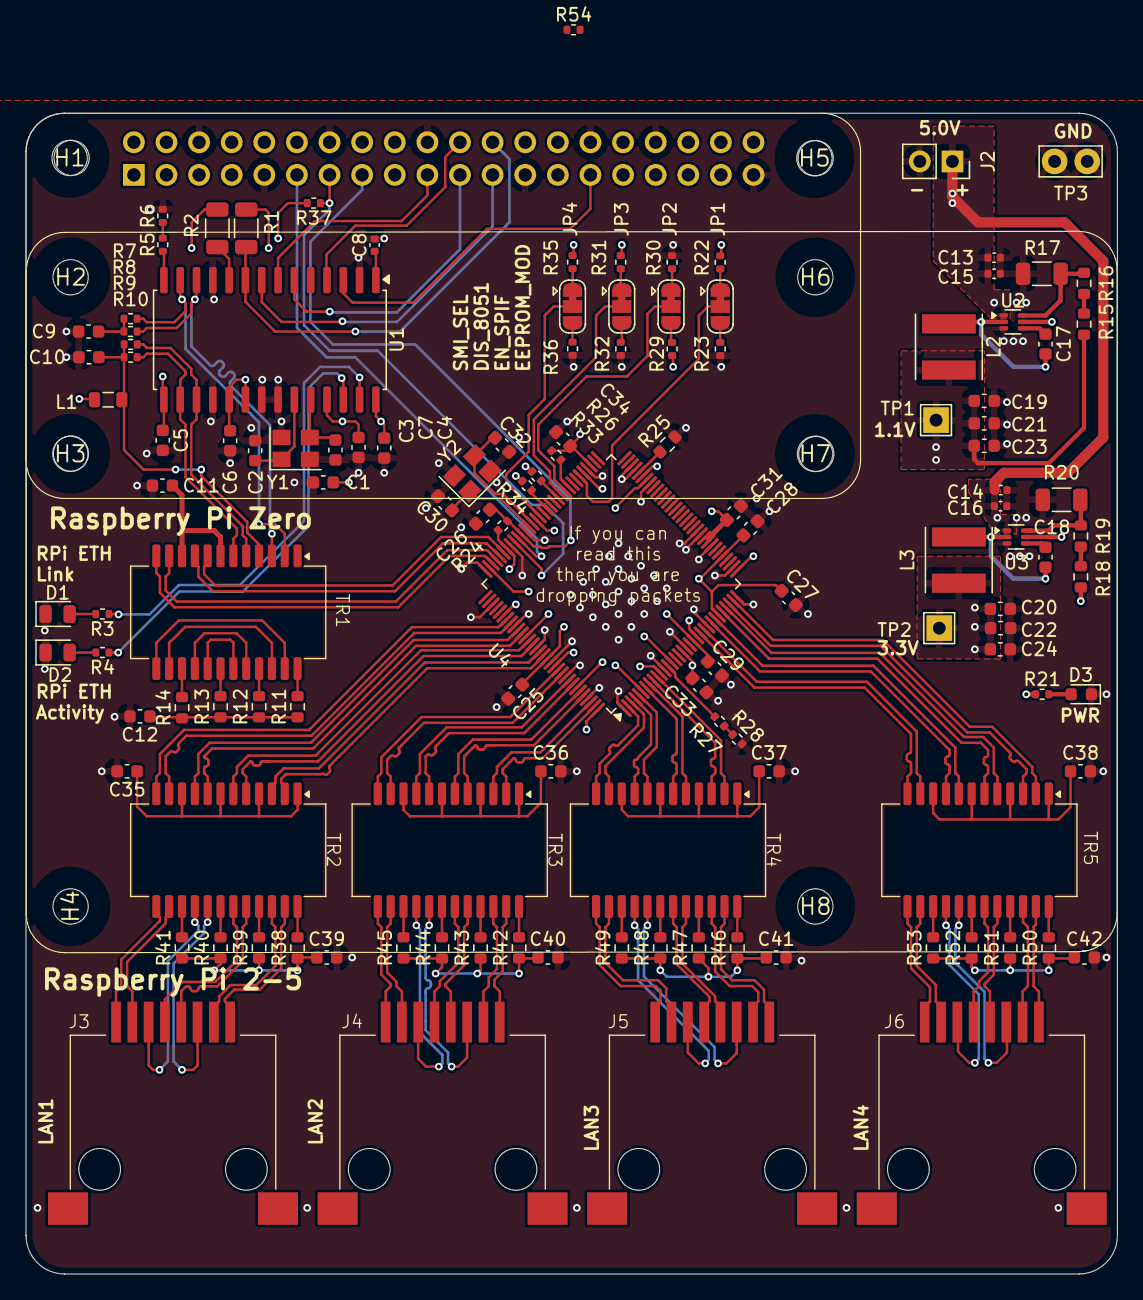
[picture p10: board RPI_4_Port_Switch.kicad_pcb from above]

Board: 4 copper layers, 85.0 x 90.4 mm, 134 parts (1 on the bottom side), 160 nets.

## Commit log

2025-03-03 Initial KiCAD project commit
    [RPI_4_Port_Switch.kicad_pcb, RPI_4_Port_Switch.kicad_sch, bom.csv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]
2025-05-14 Add Raspberry Pi 5 picture
